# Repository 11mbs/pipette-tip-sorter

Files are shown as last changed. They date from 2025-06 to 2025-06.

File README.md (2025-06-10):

# pipette-tip-sorter

This project is a remix of [Vapecream's design on Printables](https://www.printables.com/model/896781-modular-pippette-tip-sorting-box) but has been re-written to be parametric, and easily customised.  

The STL files provided use parameters for 200µl tips but there are dimensions for 10µl pipettes included in the SCAD file.
    - _Note that the 10µl designs are not perfected and still have issues that need more testing_  

### Assembly:
To attach the lid to the box, feed a length of 1.75mm PLA filament through the hinge parts and use a soldering iron / hot tool to flatten the ends so it does not fall out.
Stiff wire also works.  

### Usage:
1) Slide the upper comb into the box.
2) Put between 30 to 40 tips into the box.
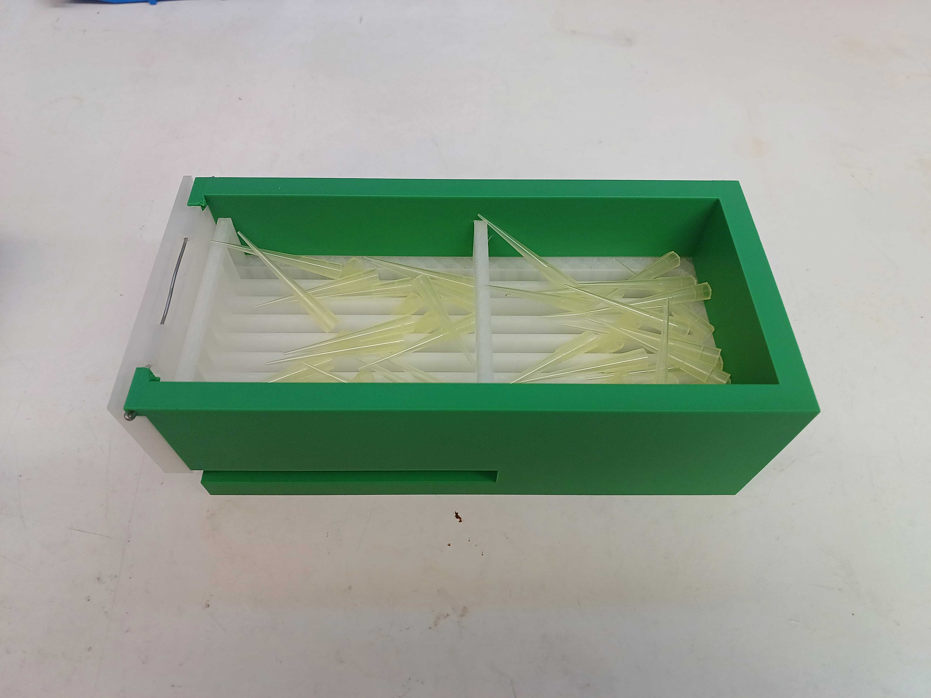
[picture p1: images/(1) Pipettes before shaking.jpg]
Before shaking

3) Shake the box until most of the pipettes have fallen into place. You may have to help some of them.
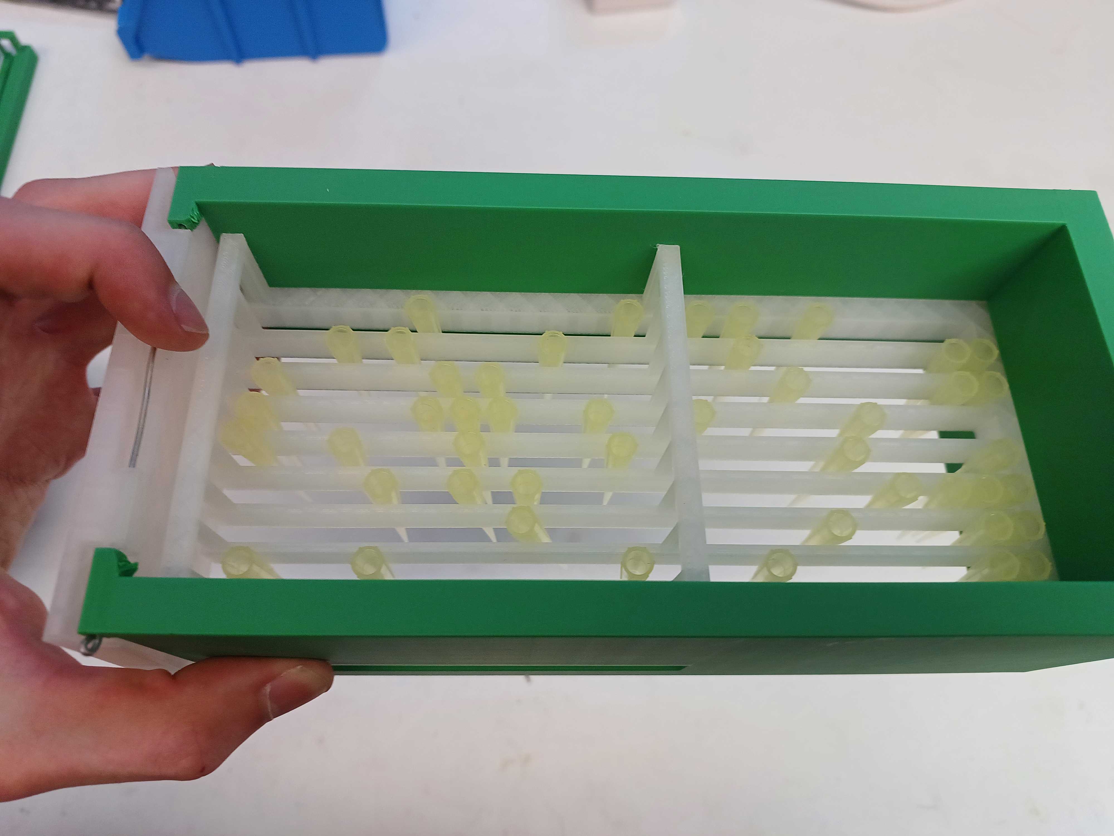
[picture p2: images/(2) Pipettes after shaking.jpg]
After shaking

4) Once the tips are sitting in the upper comb, slide them towards the lid.
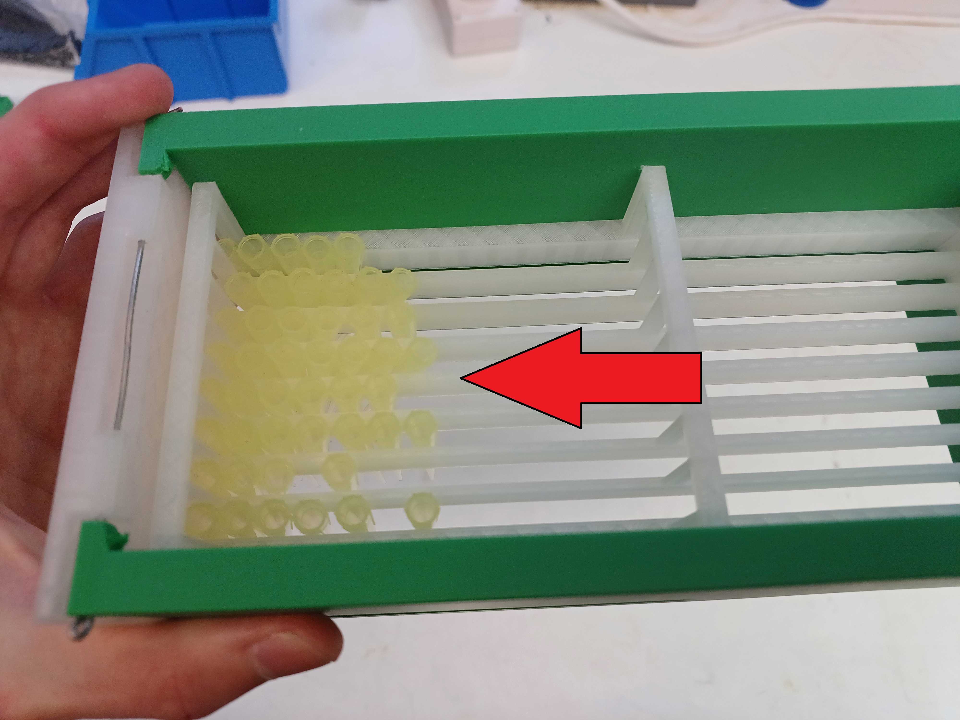
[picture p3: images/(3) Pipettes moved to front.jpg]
Slid to the front

5) Add 20 to 30 more tips and repeat the process of shaking and sliding until all the tips are in the box.
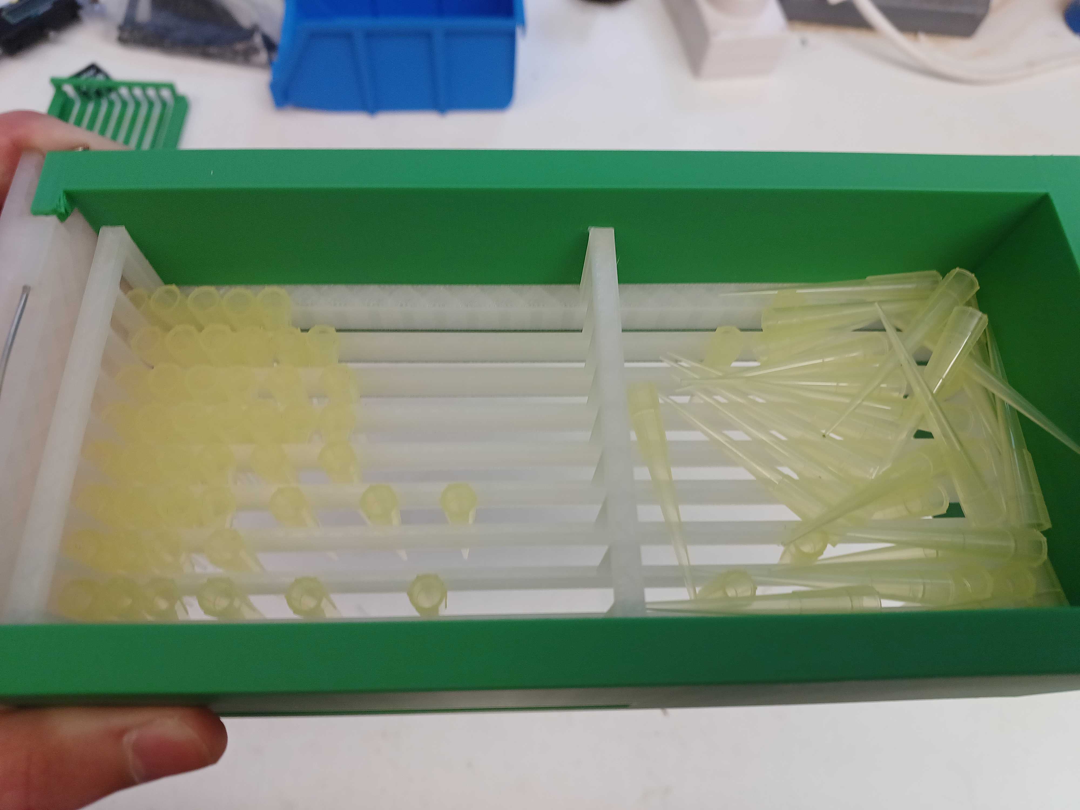
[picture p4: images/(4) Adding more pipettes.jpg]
More tips
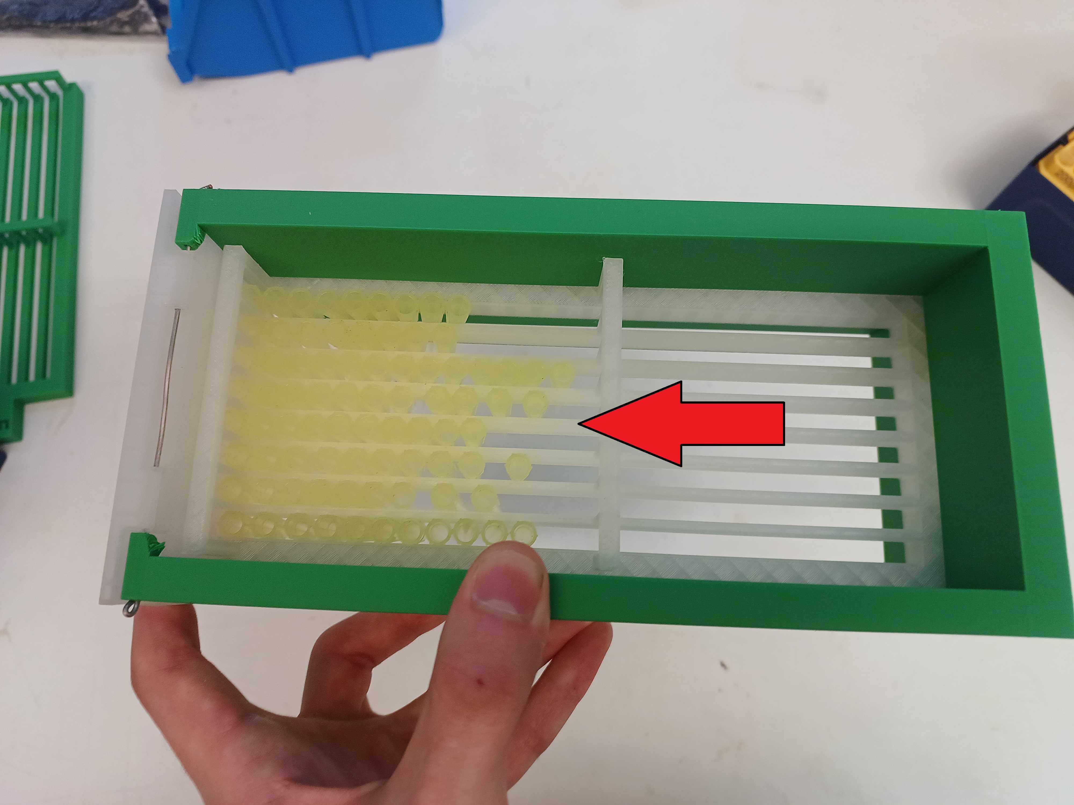
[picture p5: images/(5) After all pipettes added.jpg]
 
6) Once you have enough tips, slide the lower comb into the gap underneath the upper comb to align the pipettes for the box the pipettes will be placed into.
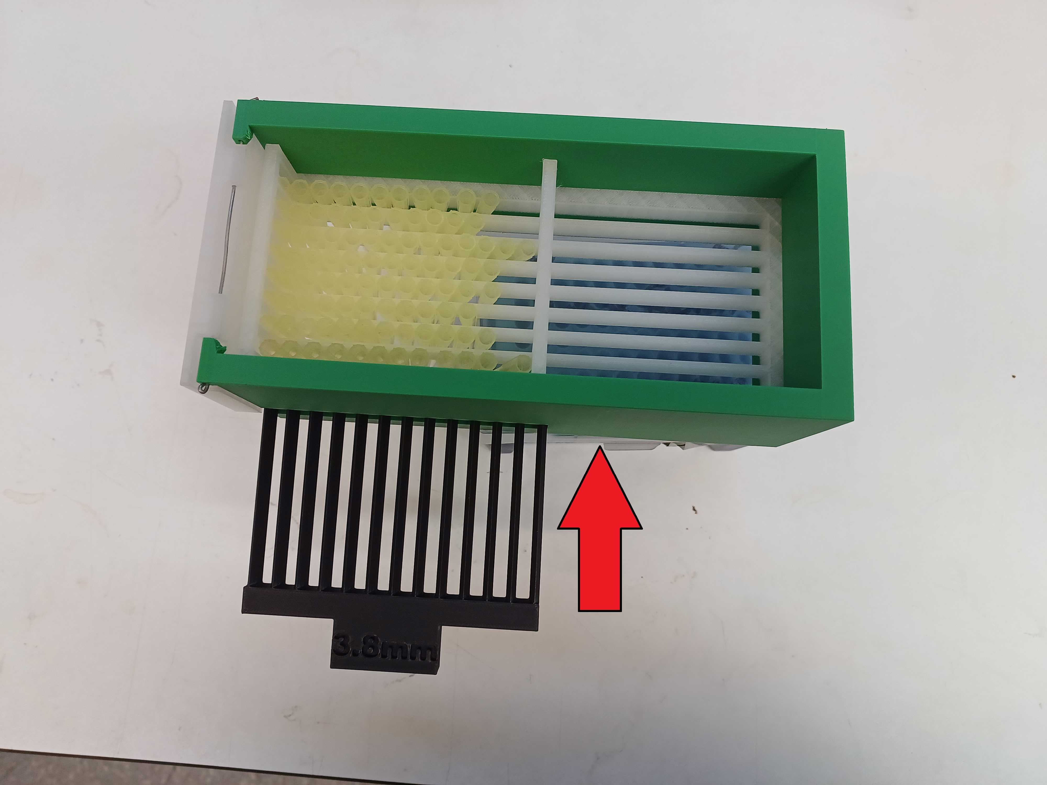
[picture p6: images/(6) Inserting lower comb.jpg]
Insert the lower comb

7) Once the lower comb is fully inserted check if any tips are squeezed into the same slot.  

* _You can pick these out manually or retry the lower comb if there are too many_.
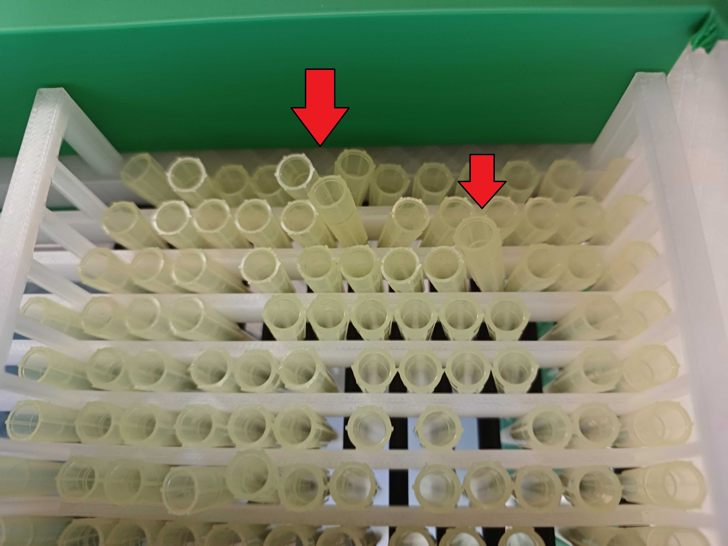
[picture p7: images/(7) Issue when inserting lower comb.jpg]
Watch out for errors

8) Slightly shake the lower comb so all the tips are aligned to fit in the box correctly.
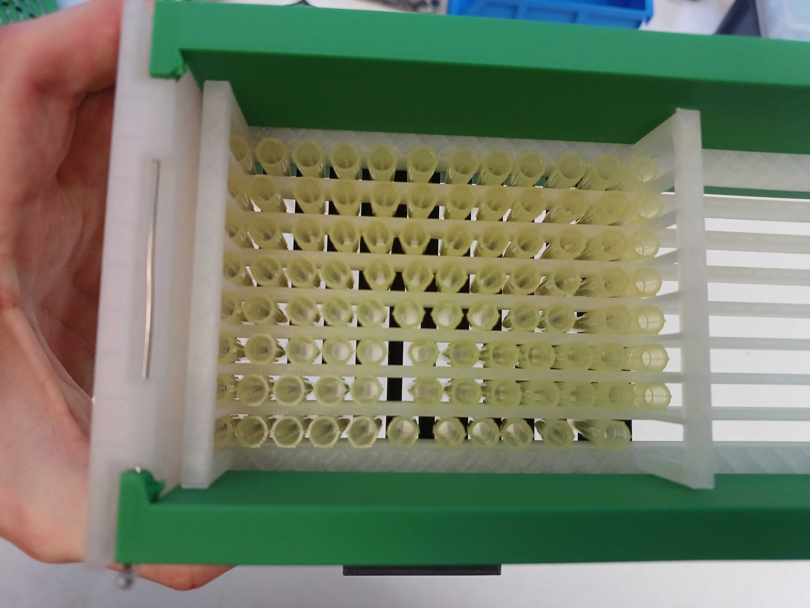
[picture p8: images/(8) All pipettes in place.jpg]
All tips in place

9) Make sure all the pipettes line up when lowering into the cassette / tip box.
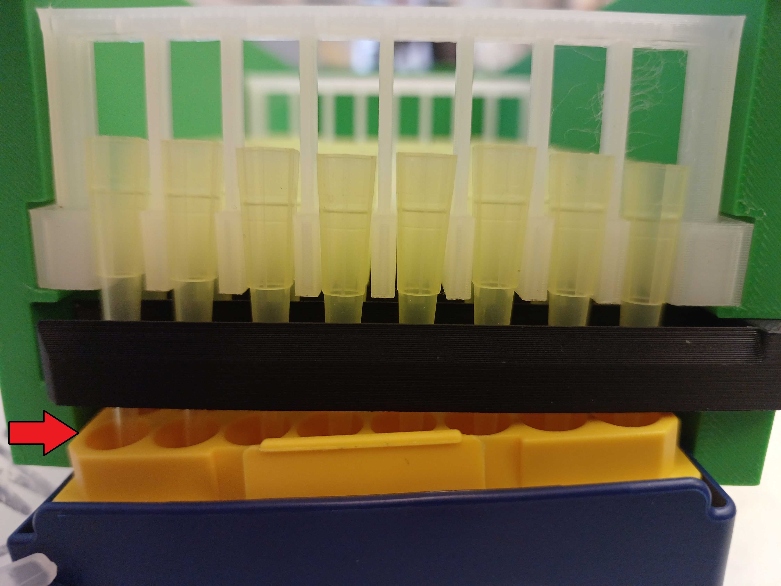
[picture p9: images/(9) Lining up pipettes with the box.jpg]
Lining up with the box

10) Hold both combs and slide them apart, keeping the lower comb and tips in place.
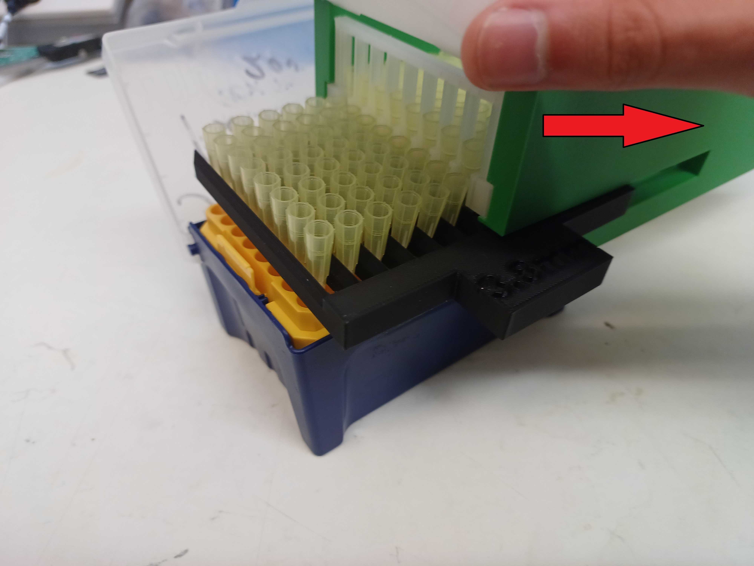
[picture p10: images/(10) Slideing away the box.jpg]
Slide away the box
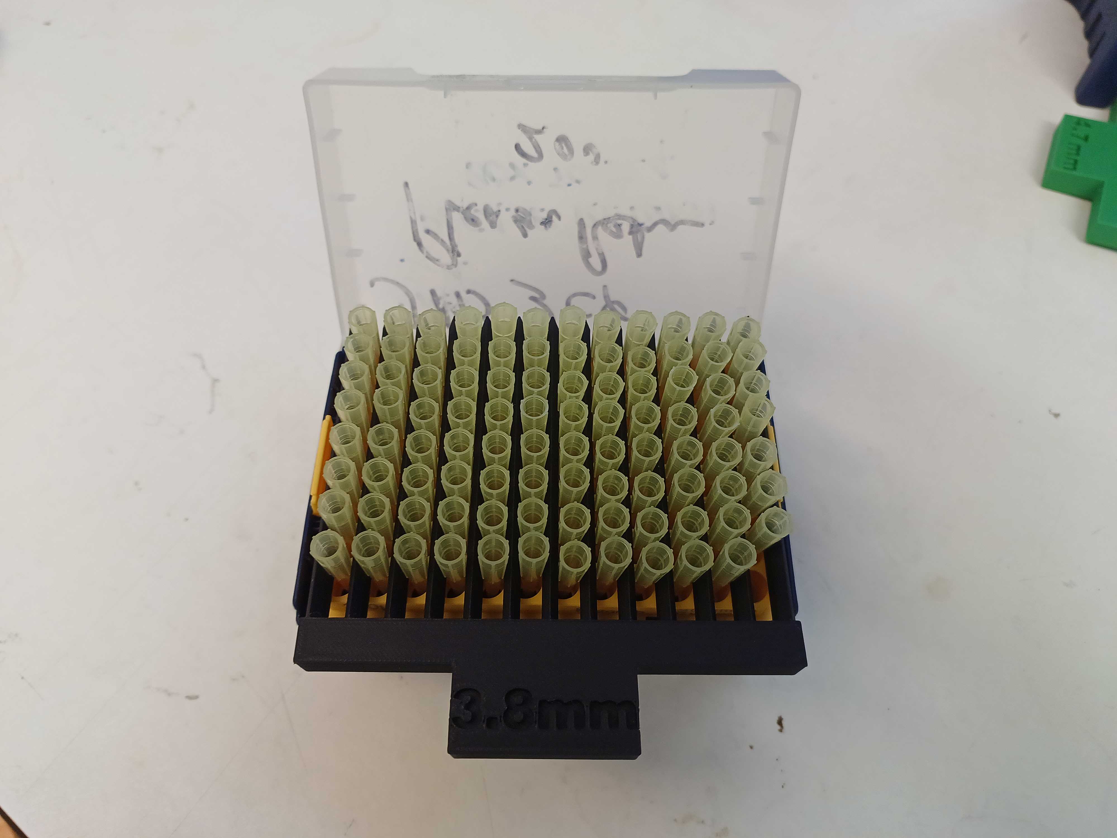
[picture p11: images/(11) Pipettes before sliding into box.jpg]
Lower comb still holding tips
 
11) Carefully slide out the lower comb and the tips should fall into place.  

* _Remember to manually add in any missing tips_
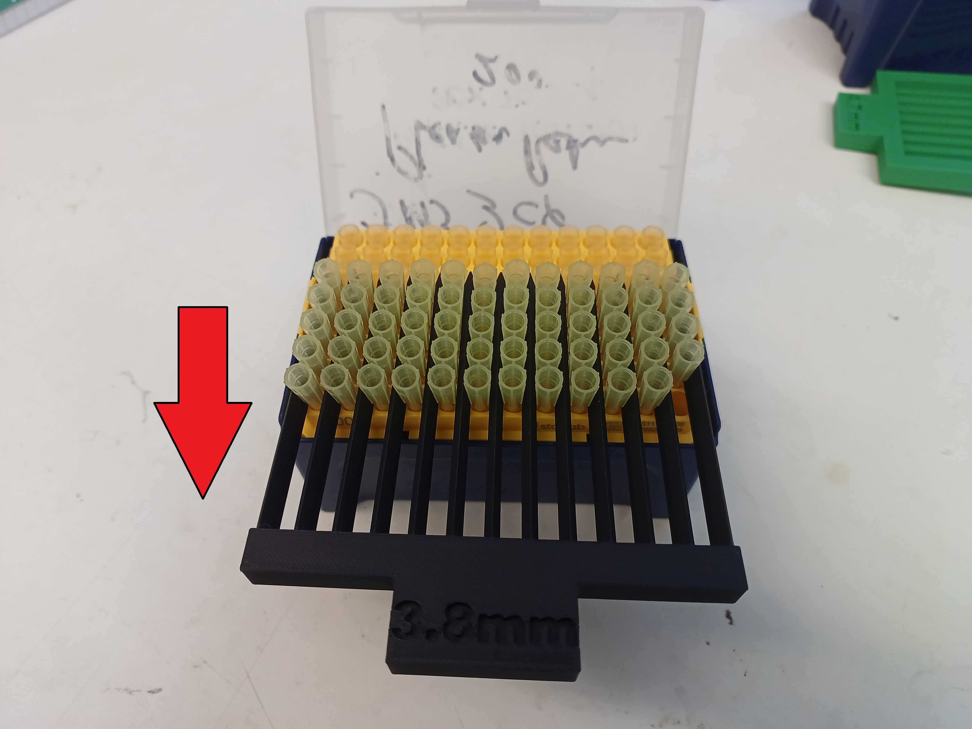
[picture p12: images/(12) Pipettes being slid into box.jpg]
Slide away the lower comb
  

:)

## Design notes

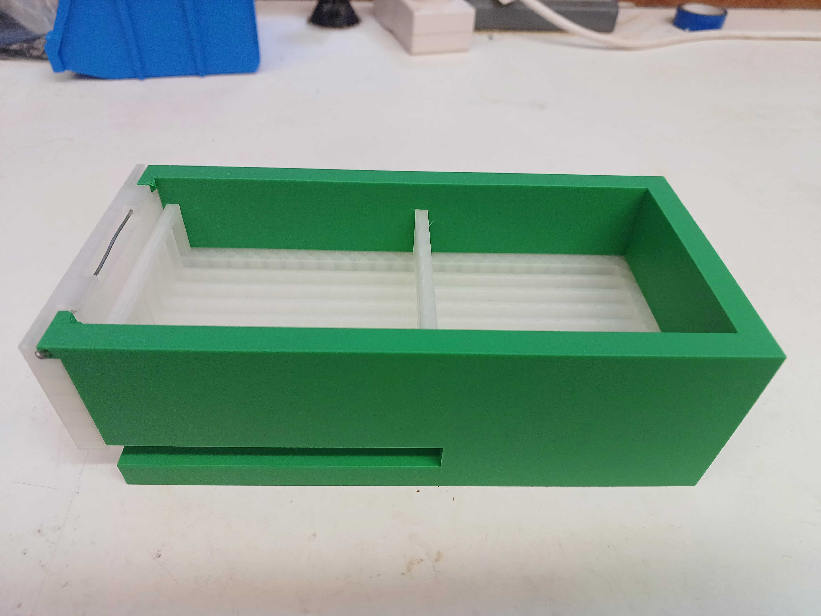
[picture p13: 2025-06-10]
images/Complete Box.jpg

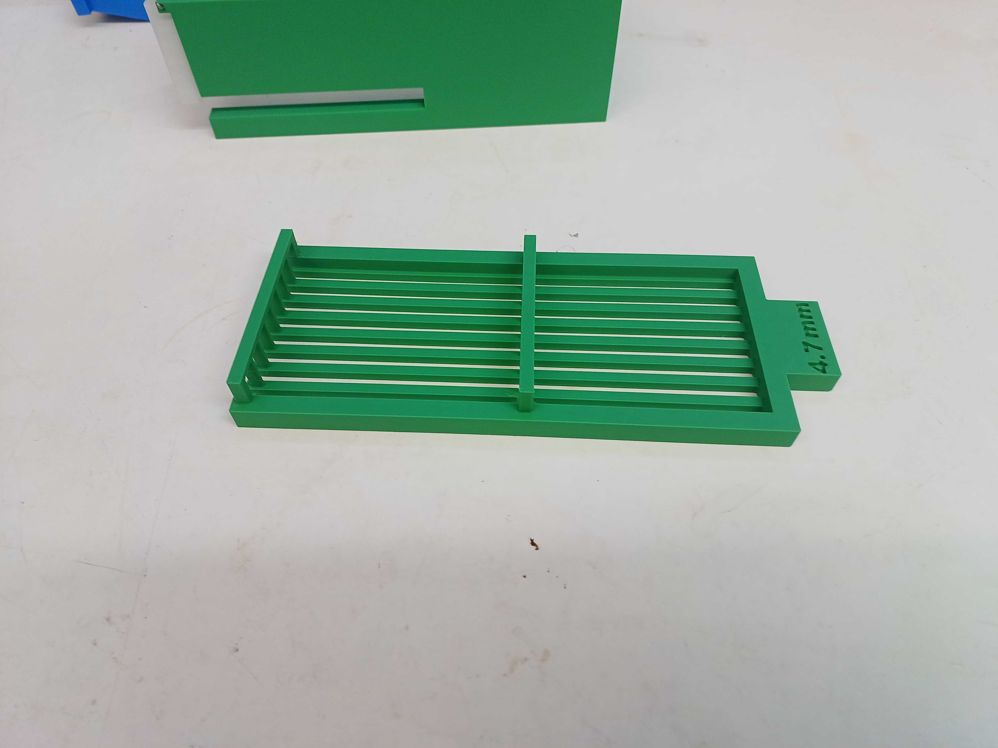
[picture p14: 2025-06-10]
images/Upper Comb.jpg

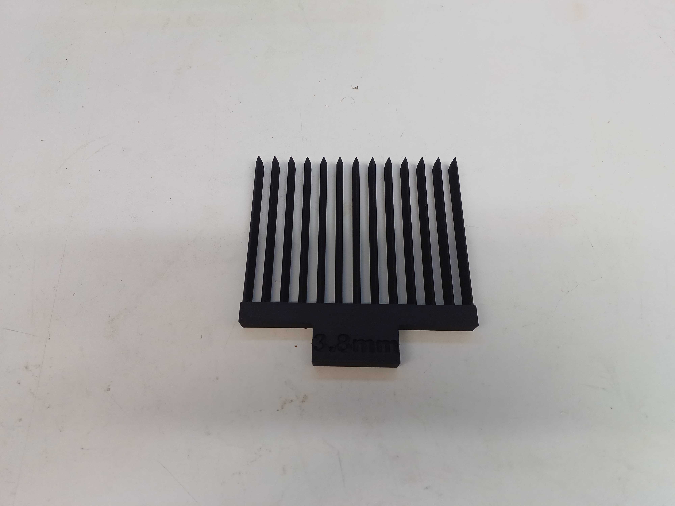
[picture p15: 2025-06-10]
images/Lower Comb.jpg

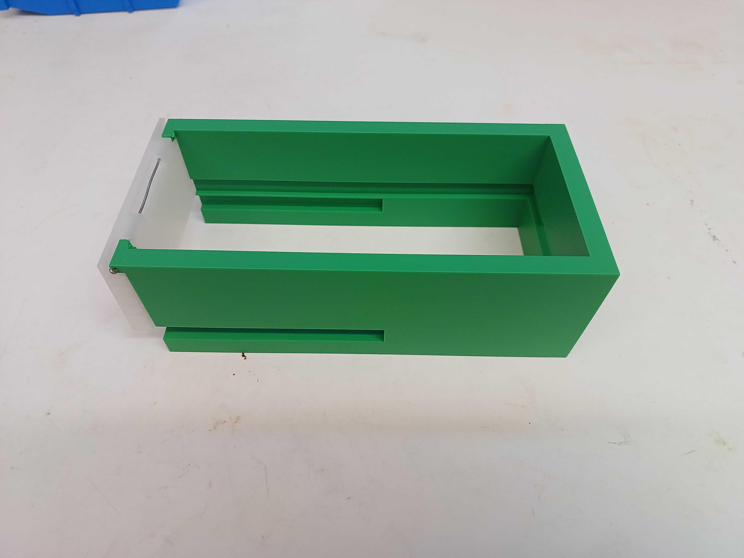
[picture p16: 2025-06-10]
images/Outer Box.jpg

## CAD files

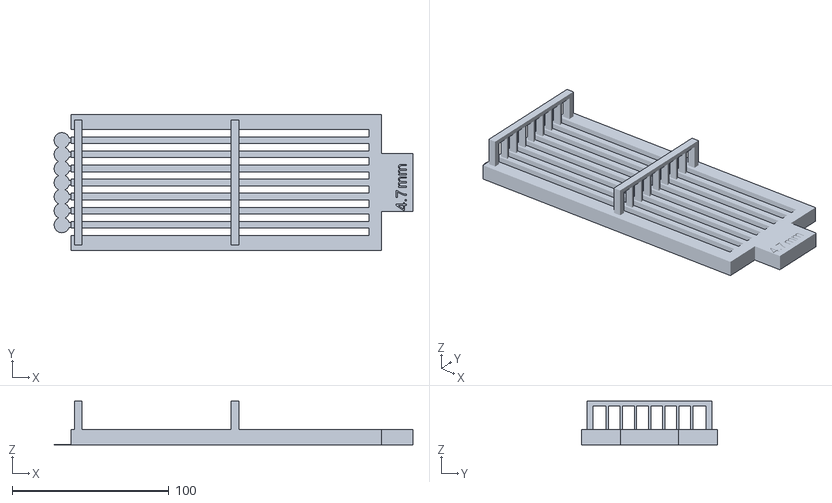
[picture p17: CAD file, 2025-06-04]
Upper Comb 200µL.stl
229.0 x 87.0 x 28.0

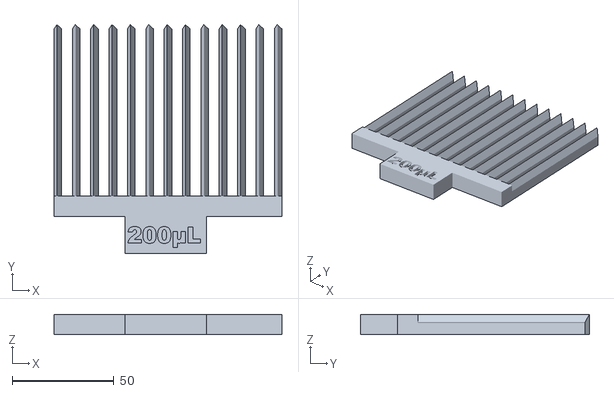
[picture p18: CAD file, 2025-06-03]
Lower Comb 200µL.stl
111.8 x 112.1 x 10.0

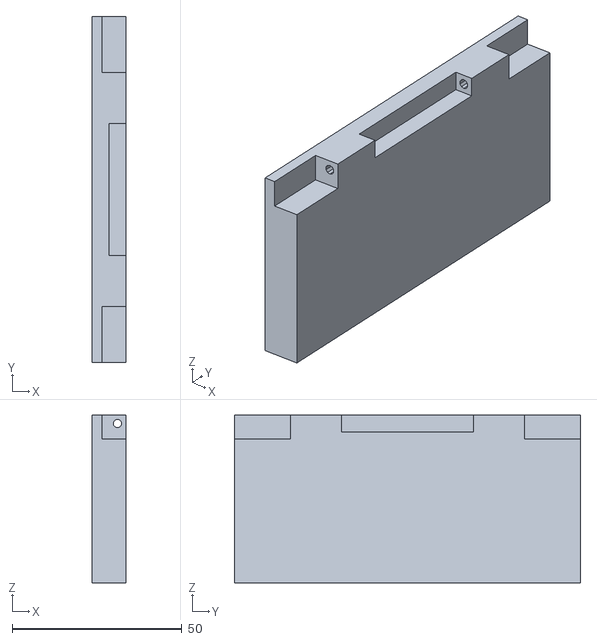
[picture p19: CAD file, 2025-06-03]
Lid.stl
10.0 x 102.0 x 49.5

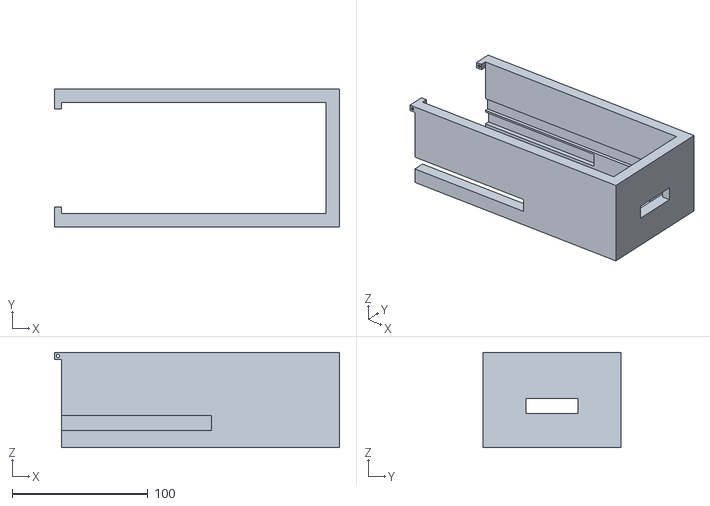
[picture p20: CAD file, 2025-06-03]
Box.stl
210.0 x 102.0 x 70.0

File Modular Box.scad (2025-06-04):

//Paramaters for 10µL Pipette
//  Comb Thickness Upper 4.7
//  Comb thickness Lower 5.9
//  Comb depth Upper 4
//  Lower Comb Angle 8


//200µL Pipette
//  Comb Thickness Upper 6.1
//  Comb Thickness Lower 3.8
//  Comb Depth Upper 10
//  Lower Comb Angle 6

pipette_name = "200µL";

   //--Box--//
box_length = 200;//not shorter then 121
box_width = 86;
//translate([-10,-15,-9.5])Sorting_Box();

   //--Lid--//
//translate([-10,-15,-5])Lid();

   //--Upper Comb--//
comb_thickness_upper = 4.7;//thickness of pipette / gap
colums = 8;
comb_depth_upper = 10;//Max 10
translate([-10,-9.0,-30])Inlay_gelb();
Upper_Comb_Support(); //for more adhesion on the bed when printing

   //--Lower Comb--//
comb_thickness_lower = 5.9;
rows = 12;
comb_offset_lower = 0.5;
Lower_Comb_Angle = 8;//Default 6
//rotate([0,0,90])translate([-27,-99.5,-13])transfer_Trey_gelb();

  //Upper Comb
module Spalten_Box_gelb(anzahl){ 
difference() {
    translate([10,-5.5,0])
        cube([box_length-10,box_width+1,10]);
    translate([10,2,comb_depth_upper])
        cube([box_length-10,box_width-14,10]);

    for (i=[0:colums-1]){
        translate([box_length/2+5,6.5+i*9,comb_depth_upper/2])
            cube([box_length-10,comb_thickness_upper,comb_depth_upper],center=true);}
}
}

module Inlay_gelb(){
translate([-10,4,30])Spalten_Box_gelb(colums);
translate([box_length-10,-1.5,30])cube([8,box_width+1,10]);
difference(){
translate([box_length-2,box_width/2-19.5,30])cube([20,37,10]);
rotate([0,0,90])translate([box_width/2-17,-box_length-14,38])linear_extrude(2)text(str(pipette_name),size=7.0,font="arial:style=black");}
translate([0,0,14])Support_Inlay_gelb();
translate([box_length/2,0,14])Support_Inlay_gelb();}

module Support_Inlay_gelb(){
translate([2,2,16])cube([5,4,comb_depth_upper+15]);
for (i = [0:colums-2]) {
        translate([2,14.3+9*i,16]) 
            cube([5,1.5,comb_depth_upper+15]);}
translate([2,box_width-8,16])cube([5,4,comb_depth_upper+15]);
translate([2,2,comb_depth_upper+31])cube([5,box_width-6,3]);}

module Upper_Comb_Support(){
for(i=[0:colums-2]){
    translate([-11.5,5.9+i*9,0.125])
        cube([3,3,0.25],center=true);}
for(i=[0:colums-2]){
    translate([-16,5.9+i*9,0.125])
        cylinder(h=0.25,r=5,center=true);}}

  //Lower Comb
module transfer_Trey_gelb(){
Spalten_gelb(rows);
translate([8,0,0])cube([10,comb_thickness_lower+rows*9,10]);
difference(){
translate([-10,comb_thickness_lower/2+35,0]) cube([20,40,10]);
rotate([0,0,270])translate([-comb_thickness_lower/2-74.0,-5,8])linear_extrude(2)text(str(pipette_name),size=8,font="arial:style=black");}}

module Spalten_gelb(anzahl){
    for (i = [0:rows])
        translate([0,i*9,0]) 
            Spitze_gelb();}


comb_width = comb_thickness_lower/1.5;

module Spitze_gelb(){
hull(){
translate([99,0,0])cube([1,comb_width/2,Lower_Comb_Angle]);
translate([99,comb_width,0])cube([1,comb_width/2,Lower_Comb_Angle]);
translate([102,comb_width/1.4+comb_offset_lower,0])cube([0.1,0.1,6]);}
 hull(){
translate([15,0,0])cube([1,comb_width/2,Lower_Comb_Angle]);
translate([15,comb_width,0])cube([1,comb_width/2,Lower_Comb_Angle]);
translate([99,0,0])cube([1,comb_width/2,Lower_Comb_Angle]);
translate([99,comb_width,0])cube([1,comb_width/2,Lower_Comb_Angle]);
translate([102,comb_width/1.4+comb_offset_lower,4])cube([0.1,0.1,6]);
translate([15,comb_width/1.4+comb_offset_lower,4])cube([0.1,0.1,6]);}}




  //Box
module Box(){
translate([0,-3,-16])cube([box_length+5,10,70]);
translate([0,box_width+3,-16])cube([box_length+5,10,70]);
translate([box_length-5,4,-16])cube([10,box_width,70]);
translate([-2.5,4.5,51.5])a();
translate([-2.5,box_width+5.5,51.5])a();}

module a(){
difference(){
cube([5,15,5],center=true);
rotate([0,90,90])cylinder(h=15,d=2.5,$fn=10,center=true);}}

module Sorting_Box(){
difference(){
Box();  
translate([0,4,9])cube([box_length-2,box_width+2,11]);
translate([box_length-2,box_width/2-14,9])cube([15,38,11]);
translate([0,-3,-3.5])cube([comb_thickness_lower+rows*9-1,box_width+10,11]);}}



  //Lid
module Lid(){
 difference(){
translate([-10,-3,0])cube([10,box_width+16,49.5]);
translate([-5,-3,44.5])cube([5,box_width+16,5]);
translate([-7,-3,42.5])cube([7,16.5,7]);
translate([-7,box_width-3.5,42.5])cube([7,16.5,7]);}
translate([-2.5,21,47])a();
translate([-2.5,box_width-11,47])a();}

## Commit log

2025-03-17 Update pipette_tip_sorter.scad
    added comb module and continued on the door
    [pipette_tip_sorter.scad]
2025-03-18 Update pipette_tip_sorter.scad
    finished creating the comb and started creating the feet
    [pipette_tip_sorter.scad]
2025-03-24 Update pipette_tip_sorter.scad
    Edited door, edited feet, made body taller
    [pipette_tip_sorter.scad]
2025-03-25 Update pipette_tip_sorter.scad
    Updated door to work at different sizes, changed the sizes of the feet
    [pipette_tip_sorter.scad]
2025-03-31 Update pipette_tip_sorter.scad
    Changed door to a sliding door, fixed the feet to be aligned correctly with the comb
    [pipette_tip_sorter.scad]
2025-04-01 Update pipette_tip_sorter.scad
    changing size of door,
    [pipette_tip_sorter.scad]
2025-04-07 Update pipette_tip_sorter.scad
    moved door holder
    [pipette_tip_sorter.scad]
2025-04-28 Update pipette_tip_sorter.scad
    Changed the feet design
    [pipette_tip_sorter.scad]
2025-06-03 Completed pipette tip sorter
    [Modular Box.scad]
2025-06-03 Completed pipette tip sorter with STL
    [Box.stl, Lid.stl, Lower Comb 200µL.stl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]
2025-06-04 Updated upper comb stl
    Includes tabs to facilitate easy printing
    [Upper Comb 200µL.stl]
2025-06-04 Fixing readability issues
    [Modular Box.scad]
2025-06-04 Fixed pipette tip sorter
    [Modular Box.scad]
